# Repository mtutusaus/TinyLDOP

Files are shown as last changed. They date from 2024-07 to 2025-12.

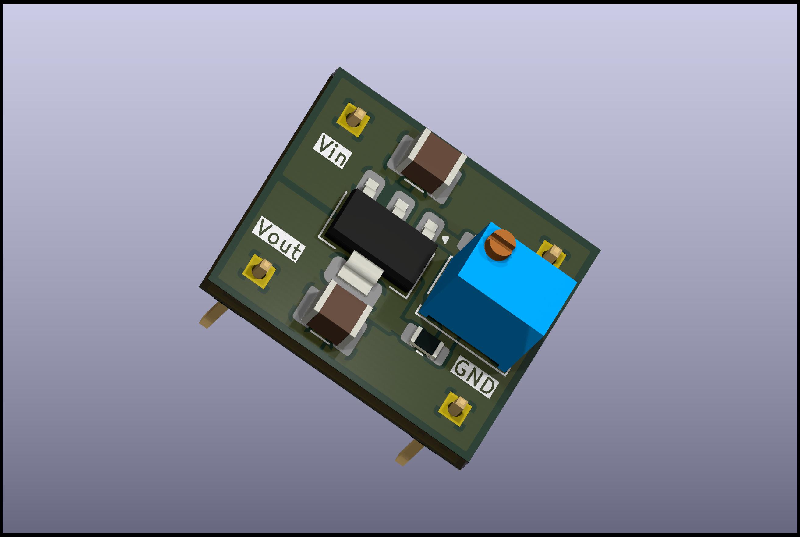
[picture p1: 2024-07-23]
pics/3dVIEW.jpg

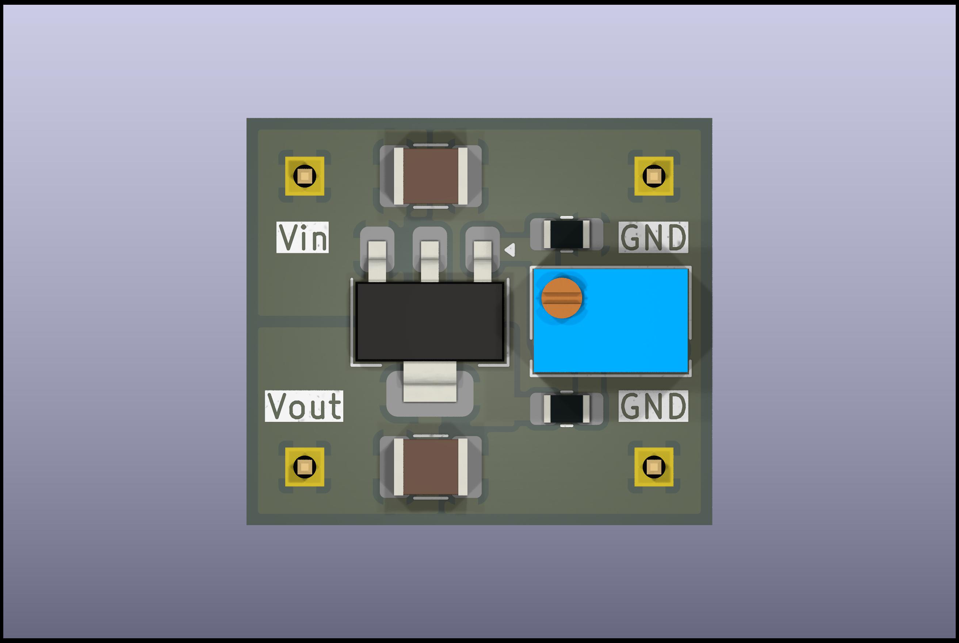
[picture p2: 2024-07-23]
pics/3dVIEW_TOP.jpg

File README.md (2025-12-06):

# TinyLAB: TinyLDOP



TinyLDOP is a breadboard-compatible linear regulator PCB for generating additional low-current voltage rails from a single power supply. It designed to be placed at the middle part of a breadboard as shown:

tiny_LDOP_breadboard

---
# **Specifications**
Considering the typical supply voltages of electronic systems, we will set the output voltage range to 1.8 – 12 V. 

According to the LM317M datasheet, the difference between input and output voltage can be as low as 2.5 V. Therefore, the input voltage range must be 4.3 – 14.5 V (which we will round to 5 – 15 V)

The maximum output current depends on the input-output voltage difference and the maximum power the device is able to dissipate. Taking into account the worst case: input voltage equal to 15 V, output voltage equal to 1.8 V and considering the package is able to dissipate 750 mW with a small heatsink, the maximum output current is 57 mA, which we will round to 50 mA.

| Specification | Value |
|---|---|
| Input voltage range [V]  | 5–15 |
| Output voltage range [V] | 1.8–12  |
| Maximum output current [mA] | 50  |

---
## **License**
This project is licensed under the [Creative Commons Attribution-NonCommercial-ShareAlike 4.0 International License](http://creativecommons.org/licenses/by-nc-sa/4.0/).

You are free to:
- **Share** — copy and redistribute the material in any medium or format
- **Adapt** — remix, transform, and build upon the material

Under the following terms:
- **Attribution** — You must give appropriate credit
- **NonCommercial** — You may not use the material for commercial purposes
- **ShareAlike** — Derivatives must use the same license

See the [LICENSE](LICENSE) file for the full license text.

---
## Author

[Miquel Tutusaus](https://github.com/mtutusaus), 2024

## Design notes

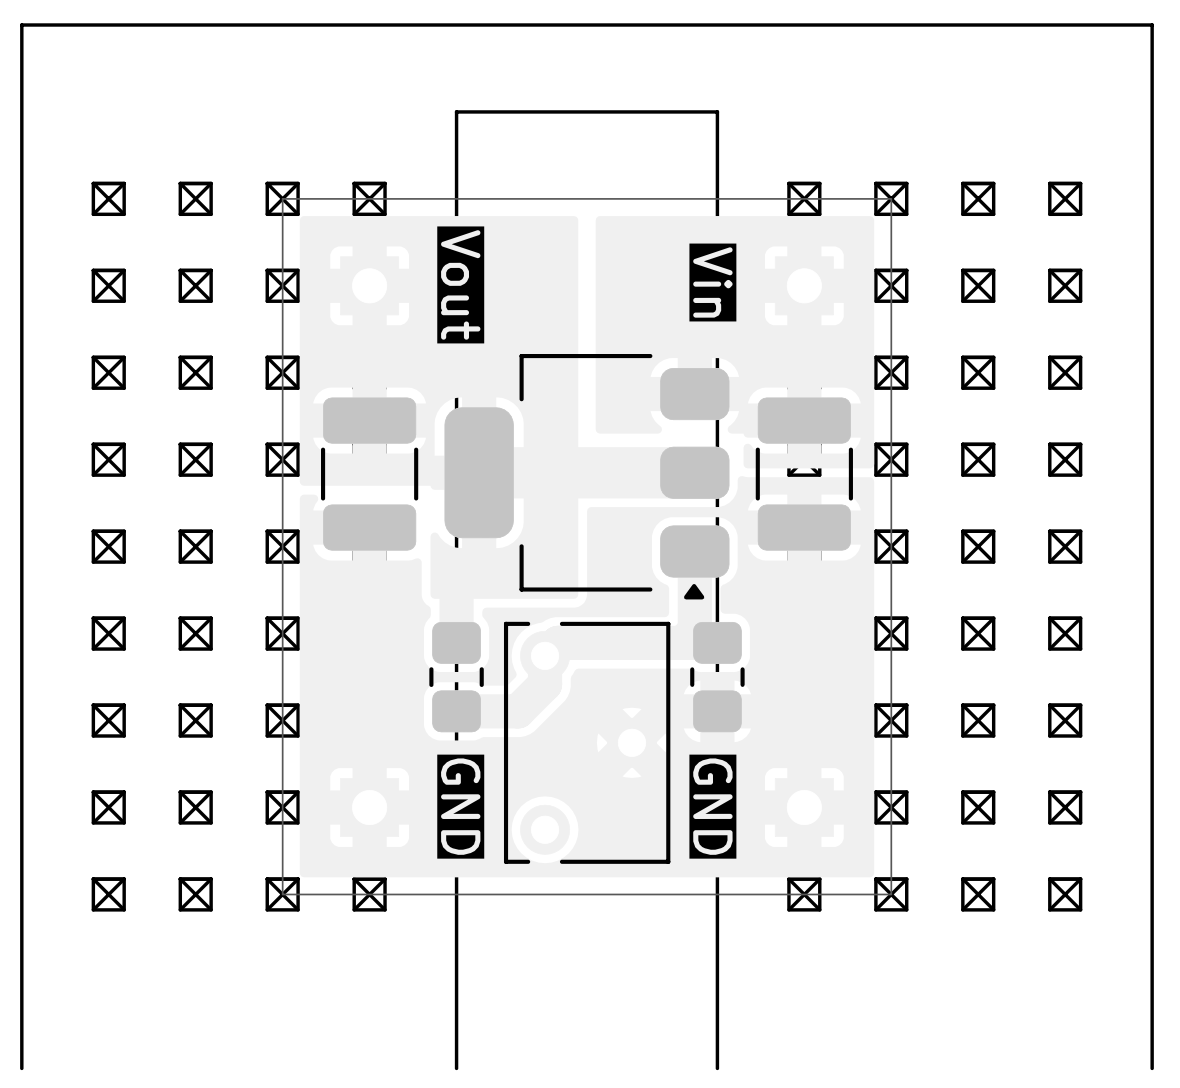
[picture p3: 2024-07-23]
pics/tiny_LDOP_breadboard.png

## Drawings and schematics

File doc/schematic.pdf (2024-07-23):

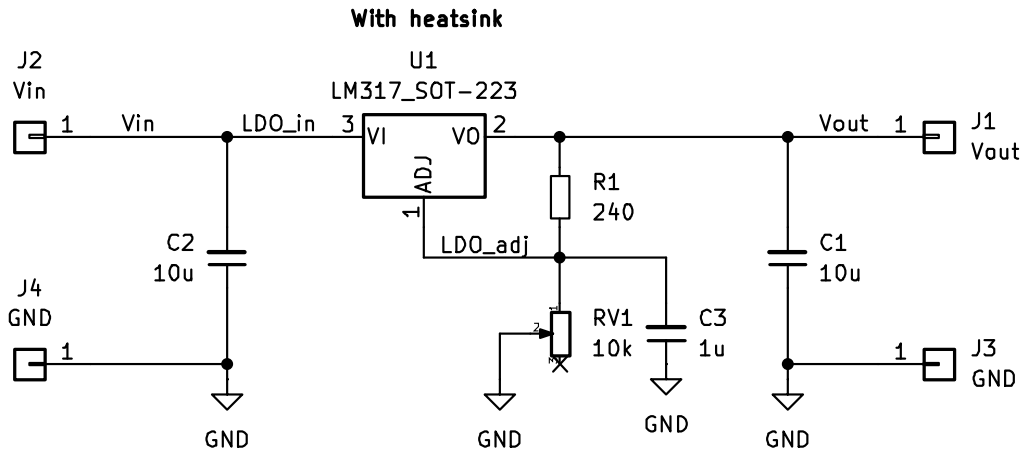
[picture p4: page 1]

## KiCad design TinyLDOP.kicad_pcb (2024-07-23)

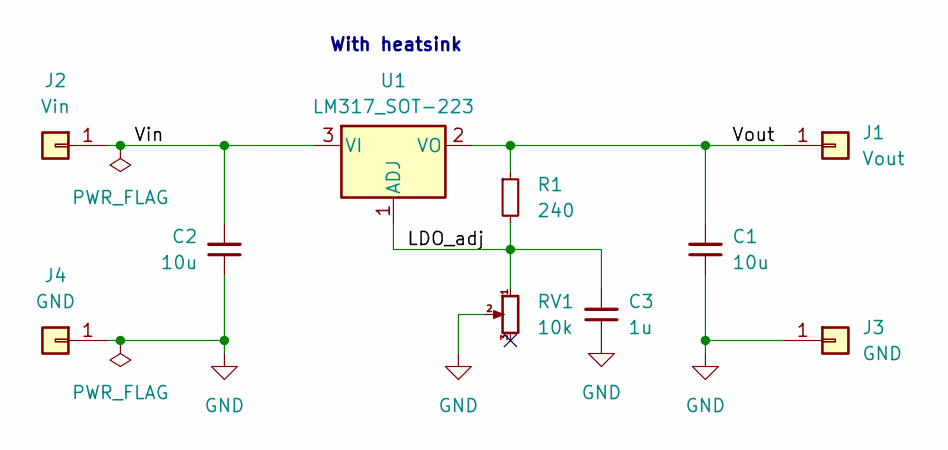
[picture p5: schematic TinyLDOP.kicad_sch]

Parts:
C1, C2: 10u; C_1210_3225Metric_Pad1.33x2.70mm_HandSolder
C3: 1u; R_0805_2012Metric_Pad1.20x1.40mm_HandSolder
J1: Vout; PinHeader_1x01_P2.54mm_Vertical
J2: Vin; PinHeader_1x01_P2.54mm_Vertical
J3, J4: GND; PinHeader_1x01_P2.54mm_Vertical
R1: 240; R_0805_2012Metric_Pad1.20x1.40mm_HandSolder
RV1: 10k; Potentiometer_Bourns_3266W_Vertical
U1: LM317_SOT-223; SOT-223-3_TabPin2

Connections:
/LDO_adj: C3.2, R1.2, RV1.1, U1.1 (ADJ)
/Vin: C2.2, J2.1, U1.3 (VI)
/Vout: C1.2, J1.1, R1.1, U1.2 (VO)
GND: C1.1, C2.1, C3.1, J3.1, J4.1, RV1.2

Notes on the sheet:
With heatsink

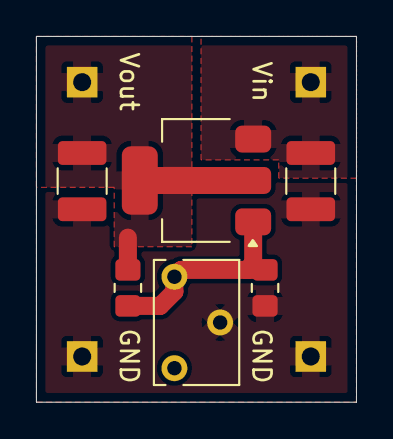
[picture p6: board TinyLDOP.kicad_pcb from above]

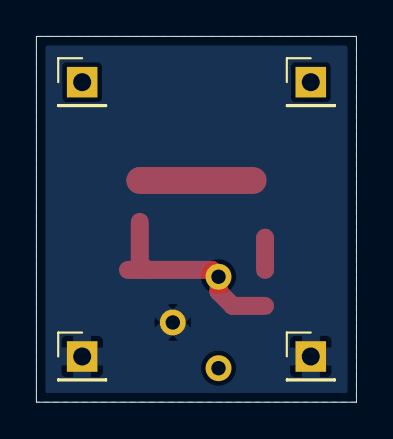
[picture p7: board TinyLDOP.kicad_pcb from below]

Board: 2 copper layers, 17.8 x 20.3 mm, 10 parts (4 on the bottom side), 4 nets.
